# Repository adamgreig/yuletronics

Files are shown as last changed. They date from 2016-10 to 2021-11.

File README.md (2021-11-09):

# Yuletronics: Electronics Club Project Michaelmas 2016

This repository contains the example Yuletronics project for Electronics Club. 
You can either use git to clone it, or simply download it 
[here](https://github.com/adamgreig/yuletronics/archive/master.zip).

You'll need KiCAD to open and edit the PCB: [download it 
here](http://kicad.org/). If you can easily get a nightly build, they have 
a few nice new features.

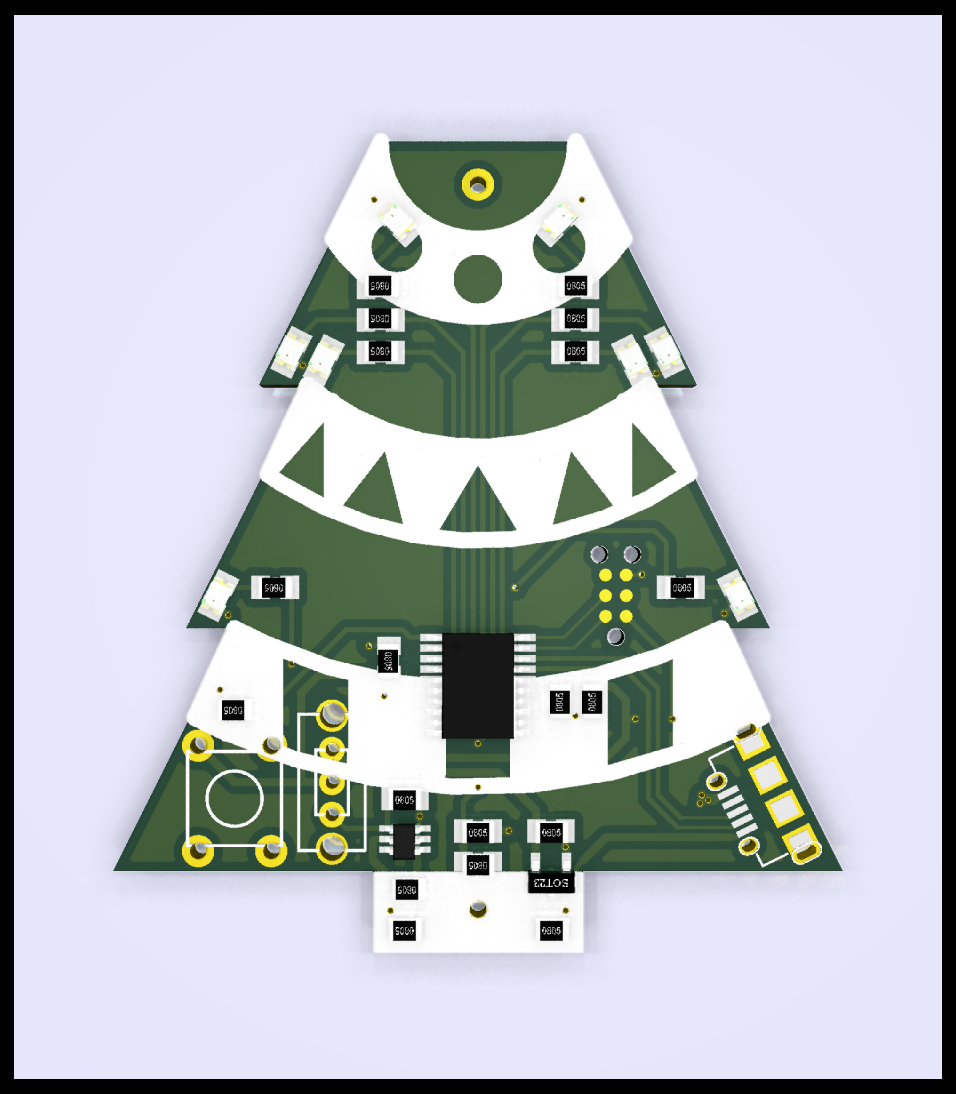
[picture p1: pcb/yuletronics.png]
3d render


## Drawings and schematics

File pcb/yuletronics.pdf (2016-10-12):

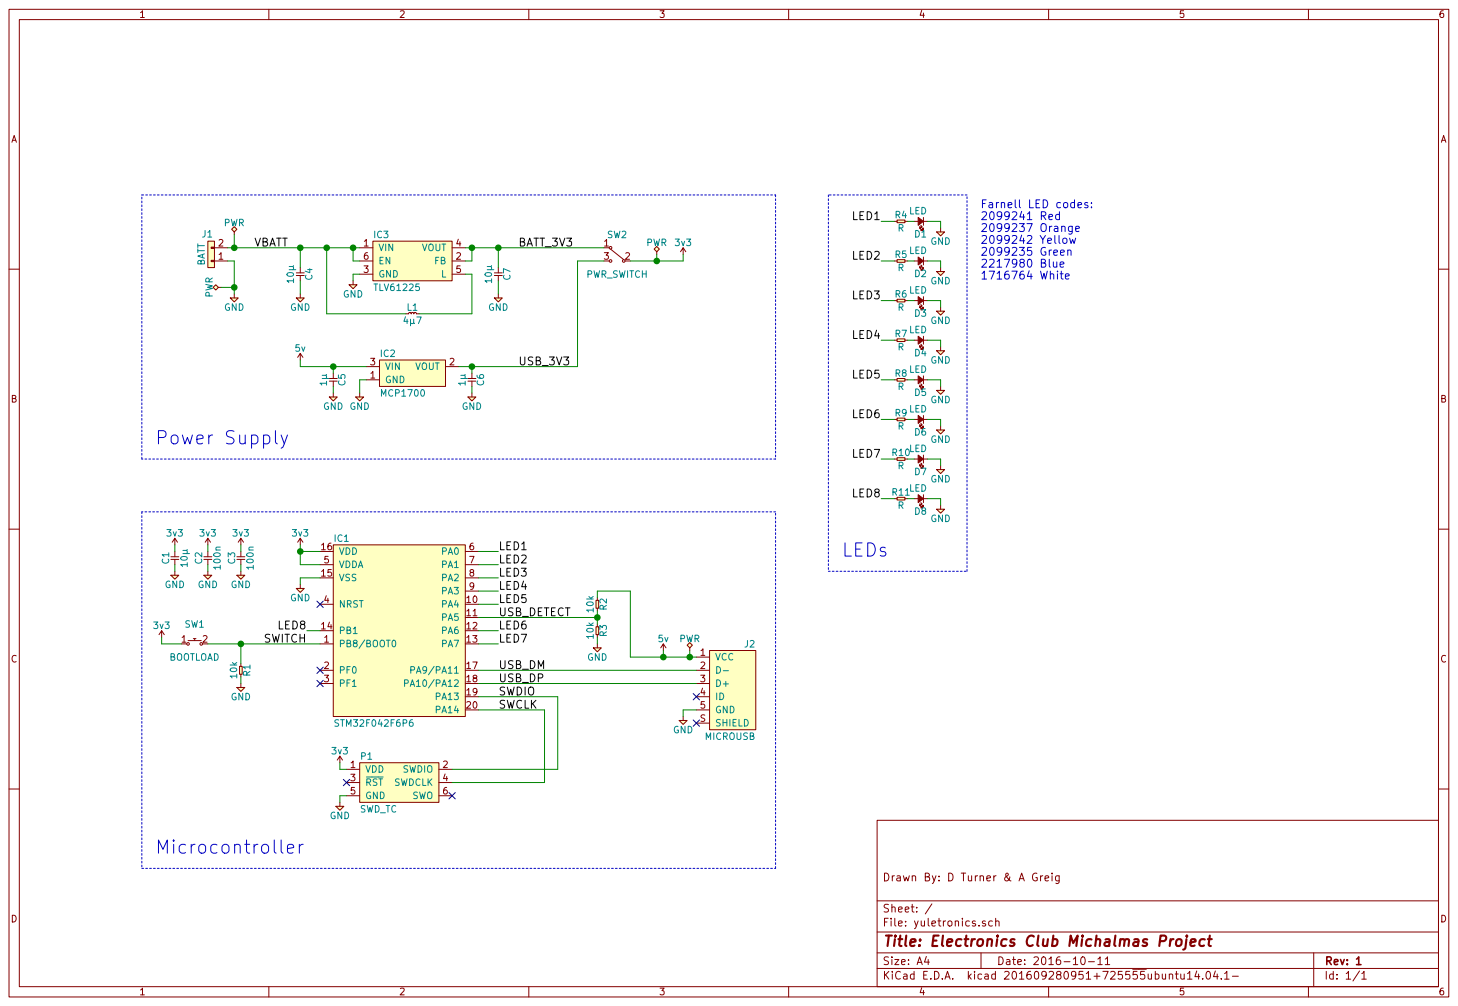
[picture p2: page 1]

SWDIO | ID 4 GND 5 SHIELD S
SWCLK

Id: 1/1 Title: Electronics Club Michalmas Project

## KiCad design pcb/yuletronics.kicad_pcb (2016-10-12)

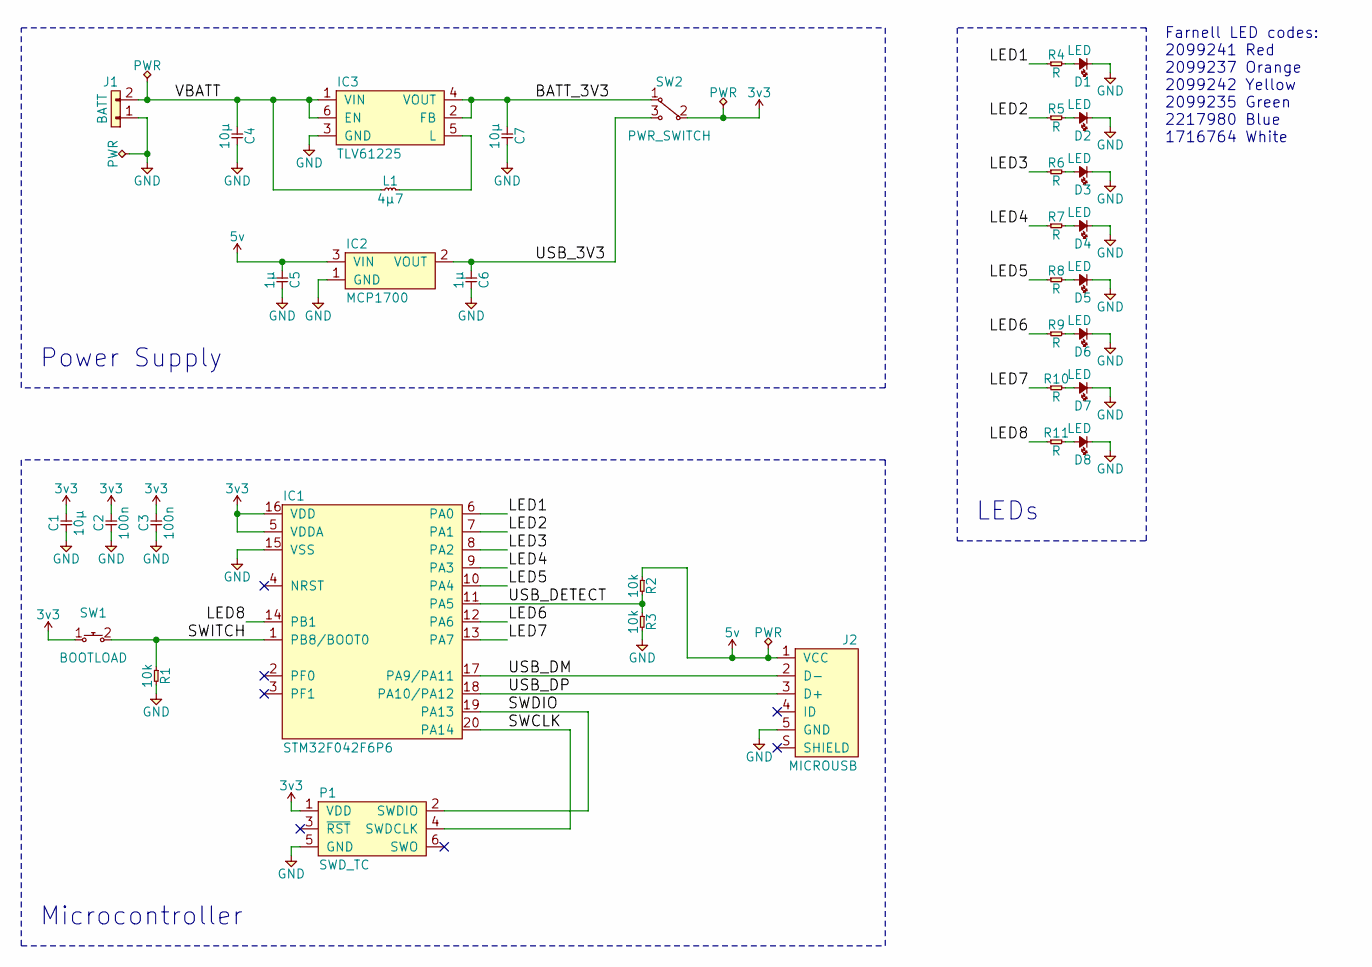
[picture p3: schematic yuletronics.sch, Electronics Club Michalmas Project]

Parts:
C1, C4, C7: 10µ; 0805; Farnell 2320851
C2, C3: 100n; 0805; Farnell 1759265
C5, C6: 1µ; 0805; Farnell 2320853
D1, D3, D5, D7: LED; 0805-LED; Farnell 2099241
D2, D4, D6, D8: LED; 0805-LED; Farnell 2099235
IC1: STM32F042F6P6; TSSOP-20; Farnell 2469549
IC2: MCP1700; SOT-23; Farnell 1296592
IC3: TLV61225; SC-70-6; Farnell 2492362
J1: BATT; AAA_HOLDER; Farnell 1702632
J2: MICROUSB; MICROUSB_MOLEX_47589-0001; Farnell 1568023
L1: 4µ7; 2016M; Farnell 2616849
P1: SWD_TC; TC2030-NL
R1, R2, R3: 10k; 0805; Farnell 9332391
R4, R5, R6, R7, R8, R9, R10, R11: R; 0805
SW1: BOOTLOAD; MOM_SWITCH; Farnell 2056809
SW2: PWR_SWITCH; SPDT_SWITCH; Farnell 1201430

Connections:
3v3: C1.2, C2.2, C3.2, IC1.5 (VDDA), IC1.16 (VDD), P1.1 (VDD), SW1.1, SW2.2
5v: C5.1, IC2.3 (VIN), J2.1 (VCC), R2.1
/BATT_3V3: C7.1, IC3.2 (FB), IC3.4 (VOUT), SW2.1
/LED1: IC1.6 (PA0), R4.1
/LED2: IC1.7 (PA1), R5.1
/LED3: IC1.8 (PA2), R6.1
/LED4: IC1.9 (PA3), R7.1
/LED5: IC1.10 (PA4), R8.1
/LED6: IC1.12 (PA6), R9.1
/LED7: IC1.13 (PA7), R10.1
/LED8: IC1.14 (PB1), R11.1
/SWCLK: IC1.20 (PA14), P1.4 (SWDCLK)
/SWDIO: IC1.19 (PA13), P1.2 (SWDIO)
/SWITCH: IC1.1 (PB8/BOOT0), R1.1, SW1.2
/USB_3V3: C6.1, IC2.2 (VOUT), SW2.3
/USB_DETECT: IC1.11 (PA5), R2.2, R3.1
/USB_DM: IC1.17 (PA9/PA11), J2.2 (D-)
/USB_DP: IC1.18 (PA10/PA12), J2.3 (D+)
/VBATT: C4.1, IC3.1 (VIN), IC3.6 (EN), J1.2, L1.1
GND: C1.1, C2.1, C3.1, C4.2, C5.2, C6.2, C7.2, D1.1, D2.1, D3.1, D4.1, D5.1, D6.1, D7.1, D8.1, IC1.15 (VSS), IC2.1 (GND), IC3.3 (GND), J1.1, J2.5 (GND), P1.5 (GND), R1.2, R3.2
unnamed: D1.2, R4.2
unnamed: D2.2, R5.2
unnamed: D3.2, R6.2
unnamed: D4.2, R7.2
unnamed: D5.2, R8.2
unnamed: D6.2, R9.2
unnamed: D7.2, R10.2
unnamed: D8.2, R11.2
unnamed: IC3.5 (L), L1.2

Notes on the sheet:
Power Supply
Microcontroller
LEDs
Farnell LED codes: 2099241 Red 2099237 Orange 2099242 Yellow 2099235 Green 2217980 Blue 1716764 White

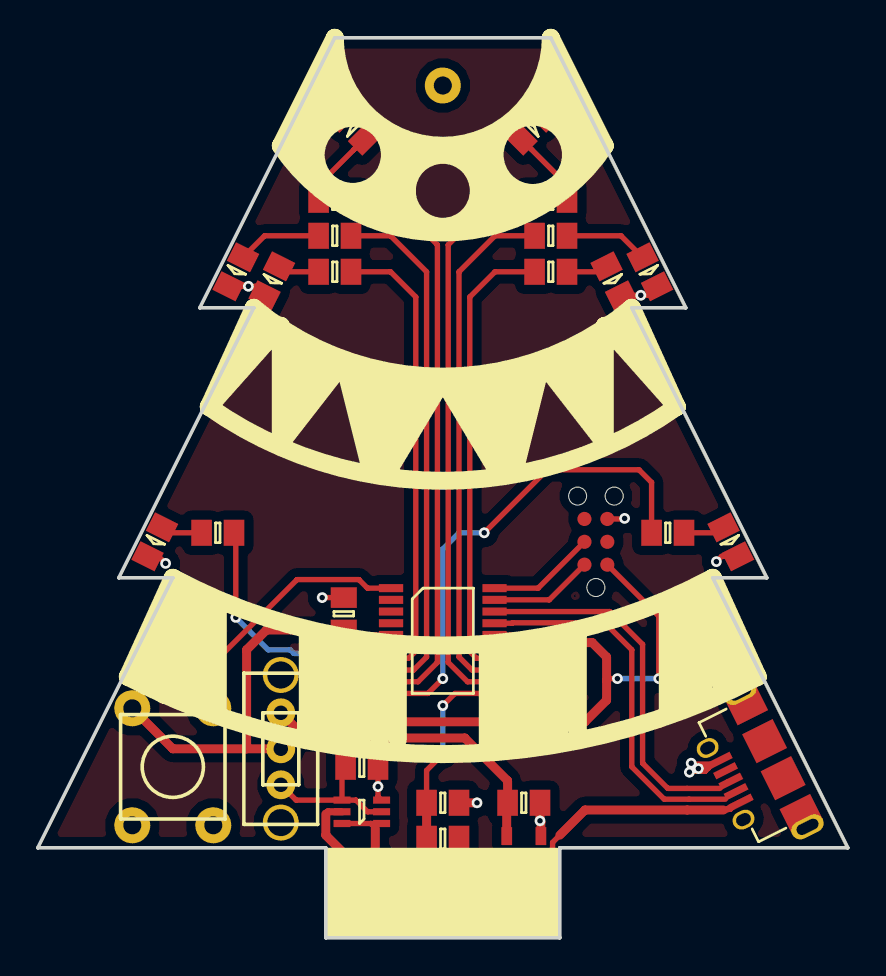
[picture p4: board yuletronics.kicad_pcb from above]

Board: 2 copper layers, 45.0 x 50.0 mm, 35 parts (1 on the bottom side), 29 nets.

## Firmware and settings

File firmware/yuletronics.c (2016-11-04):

#include <stdint.h>
#include <stdbool.h>

#include <libopencm3/stm32/rcc.h>
#include <libopencm3/stm32/gpio.h>

#define LED1 GPIO0
#define LED2 GPIO1
#define LED3 GPIO2
#define LED4 GPIO3
#define LED5 GPIO4
#define LED6 GPIO6
#define LED7 GPIO7
#define LED8 GPIO1

#define LED1_PORT GPIOA
#define LED2_PORT GPIOA
#define LED3_PORT GPIOA
#define LED4_PORT GPIOA
#define LED5_PORT GPIOA
#define LED6_PORT GPIOA
#define LED7_PORT GPIOA
#define LED8_PORT GPIOB

static const uint16_t led_pins[] = {
    0,
    LED1, LED2, LED3, LED4, LED5, LED6, LED7, LED8
};

static const uint32_t led_ports[] = {
    0,
    LED1_PORT, LED2_PORT, LED3_PORT, LED4_PORT,
    LED5_PORT, LED6_PORT, LED7_PORT, LED8_PORT
};

#define TURNON(led) gpio_set(led_ports[led], led_pins[led])
#define TURNOFF(led) gpio_clear(led_ports[led], led_pins[led])

static void gpio_setup(void)
{
    int led;

    rcc_periph_clock_enable(RCC_GPIOA);
    rcc_periph_clock_enable(RCC_GPIOB);

    for(led=1; led<=8; led++) {
        gpio_clear(led_ports[led], led_pins[led]);
        gpio_mode_setup(
            led_ports[led], GPIO_MODE_OUTPUT, GPIO_PUPD_NONE, led_pins[led]);
        gpio_set_output_options(
            led_ports[led], GPIO_OTYPE_PP, GPIO_OSPEED_LOW, led_pins[led]);
    }
}

static void wait(void)
{
    volatile int i;
    for(i=0; i<100000; i++);
}

int main(void)
{
    gpio_setup();

    while(true)
    {
        TURNON(1);
        TURNON(5);
        wait();
        TURNON(3);
        TURNON(7);
        wait();
        TURNOFF(1);
        TURNOFF(5);
        wait();
        TURNOFF(3);
        TURNOFF(7);
        TURNON(2);
        TURNON(8);
        wait();
        TURNOFF(2);
        TURNOFF(8);
    }
    return 0;
}

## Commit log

2016-10-12 Initial commit. Layout of example PCB.
    [yuletronics-B.Cu.gbl, yuletronics-B.Mask.gbs, yuletronics-B.SilkS.gbo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]
2016-10-12 Make PCB file compatibile with stable KiCAD 4.0.4
    [yuletronics.kicad_pcb]
2016-10-18 Add README
    [yuletronics-NPTH.drl, yuletronics.drl]
2016-11-04 regen bom
2016-11-04 Added USB device ID to DFU command
2021-11-09 Update README.md
    https://forum.kicad.info/t/warning-avoid-all-links-to-kicad-pcb-org-use-kicad-org/31521
